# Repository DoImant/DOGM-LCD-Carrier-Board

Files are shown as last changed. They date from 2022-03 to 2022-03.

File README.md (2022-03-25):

# Carrier board for displays of the DOGMxxxxA series.

These DOGM text displays are available in variants with 1x8 (EA DOGM081x-A), 2x16 (EA DOGM162x-A) 
and 3x16 characters (EA DOGM163x-A). The carrier board is suitable for all three variants.

This board should support all backlights (white, yellow/green, blue, red, amber, rgb full color),
but only amber was tested. The display must be connected with 3.3V.
The data transmission to the display takes place via the SPI protocol.

## DOGM LCD Datasheet

[Datasheet](https://github.com/DoImant/Stuff/blob/main/DOGM-LCD-Carrier-Board/Datasheet/dogm-lcd-eng.pdf)

## Pictures
DOGM LCD with Backlightmodule
LCD and Backlight

Carrier board front
Carrierboard front side

Carrier board back
Carrierboard back side

Carrier board with DOGM LCD
Carrier board with DOGM LCD

Display with switched off backlight.
No Backlight

Display with low regulated backlight.
Backlight 16

Display with highly regulated backlight.
Backlight 255

## Arduino Library for DOGMxxxxA Devices

[Library] (https://github.com/DoImant/Stuff/tree/main/DOGM-LCD-Carrier-Board/Arduino-Library/DOGM_7036)

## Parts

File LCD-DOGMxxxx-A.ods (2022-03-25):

Source: | C:\Users\Kai\HiDrive\users\kai-r\Elektronik\KiCad\v6\1Projects\LCD-DOGMxxxx-A\LCD-DOGMxxxx-A.kicad_sch
Date: | 24.03.2022 17:09:03
Tool: | Eeschema (6.0.4)
Generator: | D:\Programme\KiCad6\bin\scripting\plugins/bom_csv_grouped_by_value.py
Component Count: | 18
Individual Components:
Item | Qty | Reference(s) | Value | LibPart | Footprint | Datasheet
 |  | C1 | 1u | Device:C_Small | Capacitor_SMD:C_1206_3216Metric_Pad1.33x1.80mm_HandSolder | ~
 |  | C2 | 1u | Device:C_Small | Capacitor_SMD:C_1206_3216Metric_Pad1.33x1.80mm_HandSolder | ~
 |  | H1 | MountingHole | Mechanical:MountingHole | MountingHole:MountingHole_3.2mm_M3 | ~
 |  | H2 | MountingHole | Mechanical:MountingHole | MountingHole:MountingHole_3.2mm_M3 | ~
 |  | H3 | MountingHole | Mechanical:MountingHole | MountingHole:MountingHole_3.2mm_M3 | ~
 |  | H4 | MountingHole | Mechanical:MountingHole | MountingHole:MountingHole_3.2mm_M3 | ~
 |  | J1 | Conn_01x05 | Connector_Generic:Conn_01x10 | Connector_PinHeader_2.54mm:PinHeader_1x10_P2.54mm_Vertical | ~
 |  | Q1 | BC847 | Transistor_BJT:BC847 | Package_TO_SOT_SMD:SOT-23 | http://www.infineon.com/dgdl/Infineon-BC847SERIES_BC848SERIES_BC849SERIES_BC850SERIES-DS-v01_01-en.pdf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
 |  | Q2 | BC847 | Transistor_BJT:BC847 | Package_TO_SOT_SMD:SOT-23 | http://www.infineon.com/dgdl/Infineon-BC847SERIES_BC848SERIES_BC849SERIES_BC850SERIES-DS-v01_01-en.pdf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
 |  | Q3 | BC847 | Transistor_BJT:BC847 | Package_TO_SOT_SMD:SOT-23 | http://www.infineon.com/dgdl/Infineon-BC847SERIES_BC848SERIES_BC849SERIES_BC850SERIES-DS-v01_01-en.pdf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
 |  | R1 | 470 | Device:R | Resistor_SMD:R_1206_3216Metric_Pad1.30x1.75mm_HandSolder | ~
 |  | R2 | 470 | Device:R | Resistor_SMD:R_1206_3216Metric_Pad1.30x1.75mm_HandSolder | ~
 |  | R3 | 470 | Device:R | Resistor_SMD:R_1206_3216Metric_Pad1.30x1.75mm_HandSolder | ~
 |  | R4 | 470 | Device:R | Resistor_SMD:R_1206_3216Metric_Pad1.30x1.75mm_HandSolder | ~
 |  | R5 | nach Farbe | Device:R | Resistor_SMD:R_1206_3216Metric_Pad1.30x1.75mm_HandSolder | ~
 |  | R6 | 24R | Device:R | Resistor_SMD:R_1206_3216Metric_Pad1.30x1.75mm_HandSolder | ~
 |  | R7 | nach Farbe | Device:R | Resistor_SMD:R_1206_3216Metric_Pad1.30x1.75mm_HandSolder | ~
 |  | U1 | EA_DOGM081x-A | MyDisplay_Character:EA_DOGM081x-A | MyDisplay:EA_DOGMxxxx-A_55x27mm_P2.54 | https://cdn-reichelt.de/documents/datenblatt/A500/DOG-M%281%29.pdf
Collated Components:
Item | Qty | Reference(s) | Value | LibPart | Footprint | Datasheet
1 | 2 | C1, C2 | 1u | Device:C_Small | Capacitor_SMD:C_1206_3216Metric_Pad1.33x1.80mm_HandSolder | ~
2 | 4 | H1, H2, H3, H4 | MountingHole | Mechanical:MountingHole | MountingHole:MountingHole_3.2mm_M3 | ~
3 | 1 | J1 | Conn_01x05 | Connector_Generic:Conn_01x10 | Connector_PinHeader_2.54mm:PinHeader_1x10_P2.54mm_Vertical | ~
4 | 3 | Q1, Q2, Q3 | BC847 | Transistor_BJT:BC847 | Package_TO_SOT_SMD:SOT-23 | http://www.infineon.com/dgdl/Infineon-BC847SERIES_BC848SERIES_BC849SERIES_BC850SERIES-DS-v01_01-en.pdf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
5 | 4 | R1, R2, R3, R4 | 470 | Device:R | Resistor_SMD:R_1206_3216Metric_Pad1.30x1.75mm_HandSolder | ~
6 | 2 | R5, R7 | nach Farbe | Device:R | Resistor_SMD:R_1206_3216Metric_Pad1.30x1.75mm_HandSolder | ~
7 | 1 | R6 | 24R | Device:R | Resistor_SMD:R_1206_3216Metric_Pad1.30x1.75mm_HandSolder | ~
8 | 1 | U1 | EA_DOGM081x-A | MyDisplay_Character:EA_DOGM081x-A | MyDisplay:EA_DOGMxxxx-A_55x27mm_P2.54 | https://cdn-reichelt.de/documents/datenblatt/A500/DOG-M%281%29.pdf

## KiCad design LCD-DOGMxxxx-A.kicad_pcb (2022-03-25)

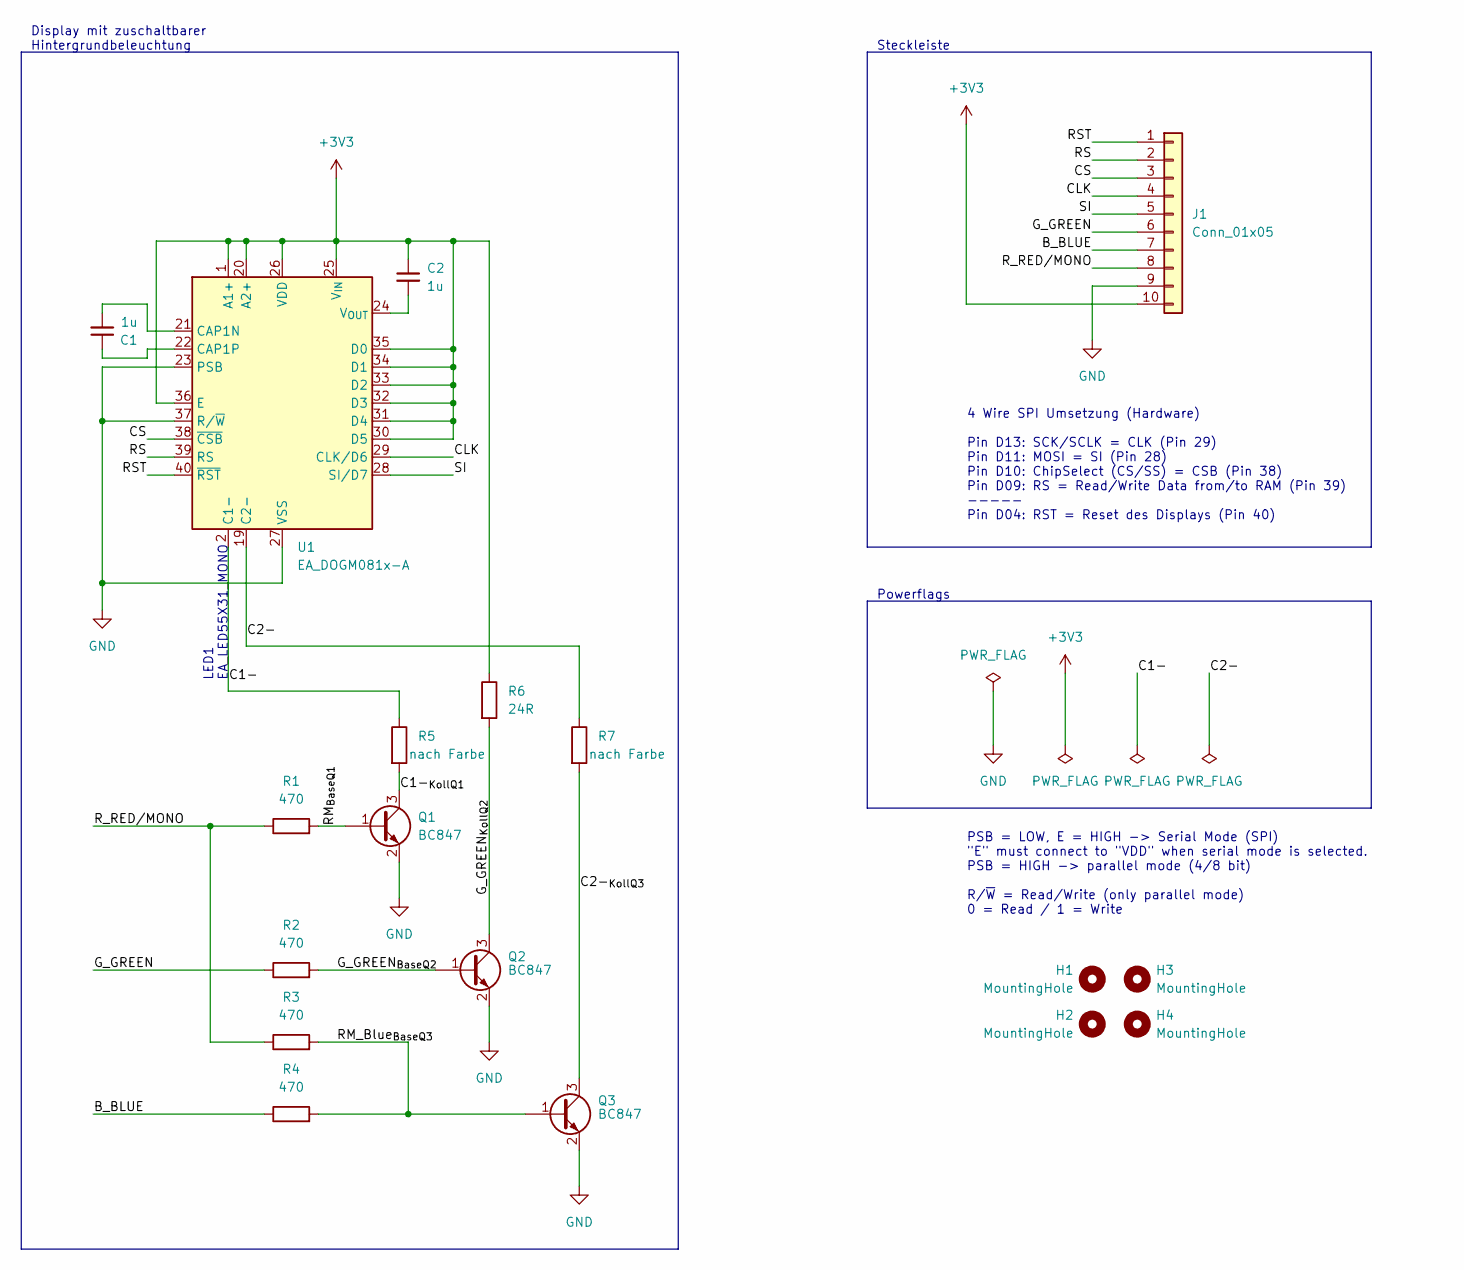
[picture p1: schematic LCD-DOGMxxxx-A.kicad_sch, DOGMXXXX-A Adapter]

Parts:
C1, C2: 1u; C_1206_3216Metric_Pad1.33x1.80mm_HandSolder
H1, H2, H3, H4: MountingHole; MountingHole_3.2mm_M3
J1: Conn_01x05; PinHeader_1x10_P2.54mm_Vertical
Q1, Q2, Q3: BC847; SOT-23
R1, R2, R3, R4: 470; R_1206_3216Metric_Pad1.30x1.75mm_HandSolder
R5, R7: nach Farbe; R_1206_3216Metric_Pad1.30x1.75mm_HandSolder
R6: 24R; R_1206_3216Metric_Pad1.30x1.75mm_HandSolder
U1: EA_DOGM081x-A; EA_DOGMxxxx-A_55x27mm_P2.54

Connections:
+3V3: C2.1, J1.10, R6.1, U1.1 (A1+), U1.20 (A2+), U1.25 (V_{IN}), U1.26 (VDD), U1.30 (D5), U1.31 (D4), U1.32 (D3), U1.33 (D2), U1.34 (D1), U1.35 (D0), U1.36 (E)
/B_BLUE: J1.7, R4.1
/C1-: R5.1, U1.2 (C1-)
/C1-_{KollQ1}: Q1.3 (C), R5.2
/C2-: R7.1, U1.19 (C2-)
/C2-_{KollQ3}: Q3.3 (C), R7.2
/CLK: J1.4, U1.29 (CLK/D6)
/CS: J1.3, U1.38 (~CSB)
/G_GREEN: J1.6, R2.1
/G_GREEN_{BaseQ2}: Q2.1 (B), R2.2
/G_GREEN_{KollQ2}: Q2.3 (C), R6.2
/RM_Blue_{BaseQ3}: Q3.1 (B), R3.2, R4.2
/RM_{BaseQ1}: Q1.1 (B), R1.2
/RS: J1.2, U1.39 (RS)
/RST: J1.1, U1.40 (~RST)
/R_RED/MONO: J1.8, R1.1, R3.1
/SI: J1.5, U1.28 (SI/D7)
GND: J1.9, Q1.2 (E), Q2.2 (E), Q3.2 (E), U1.23 (PSB), U1.27 (VSS), U1.37 (R/~W)
unnamed: C1.1, U1.22 (CAP1P)
unnamed: C1.2, U1.21 (CAP1N)
unnamed: C2.2, U1.24 (V_{OUT})

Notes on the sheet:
PSB = LOW, E = HIGH -> Serial Mode (SPI) "E" must connect to "VDD" when serial mode is selected. PSB = HIGH -> parallel mode (4/8 bit) R/~{W} = Read/Write (only parallel mode) 0 = Read / 1 = Write
Steckleiste
Display mit zuschaltbarer Hintergrundbeleuchtung
LED1 EA_LED55X31_MONO
4 Wire SPI Umsetzung (Hardware) Pin D13: SCK/SCLK = CLK (Pin 29) Pin D11: MOSI = SI (Pin 28) Pin D10: ChipSelect (CS/SS) = CSB (Pin 38) Pin D09: RS = Read/Write Data from/to RAM (Pin 39) ----- Pin D04: RST = Reset des Displays (Pin 40)
Powerflags

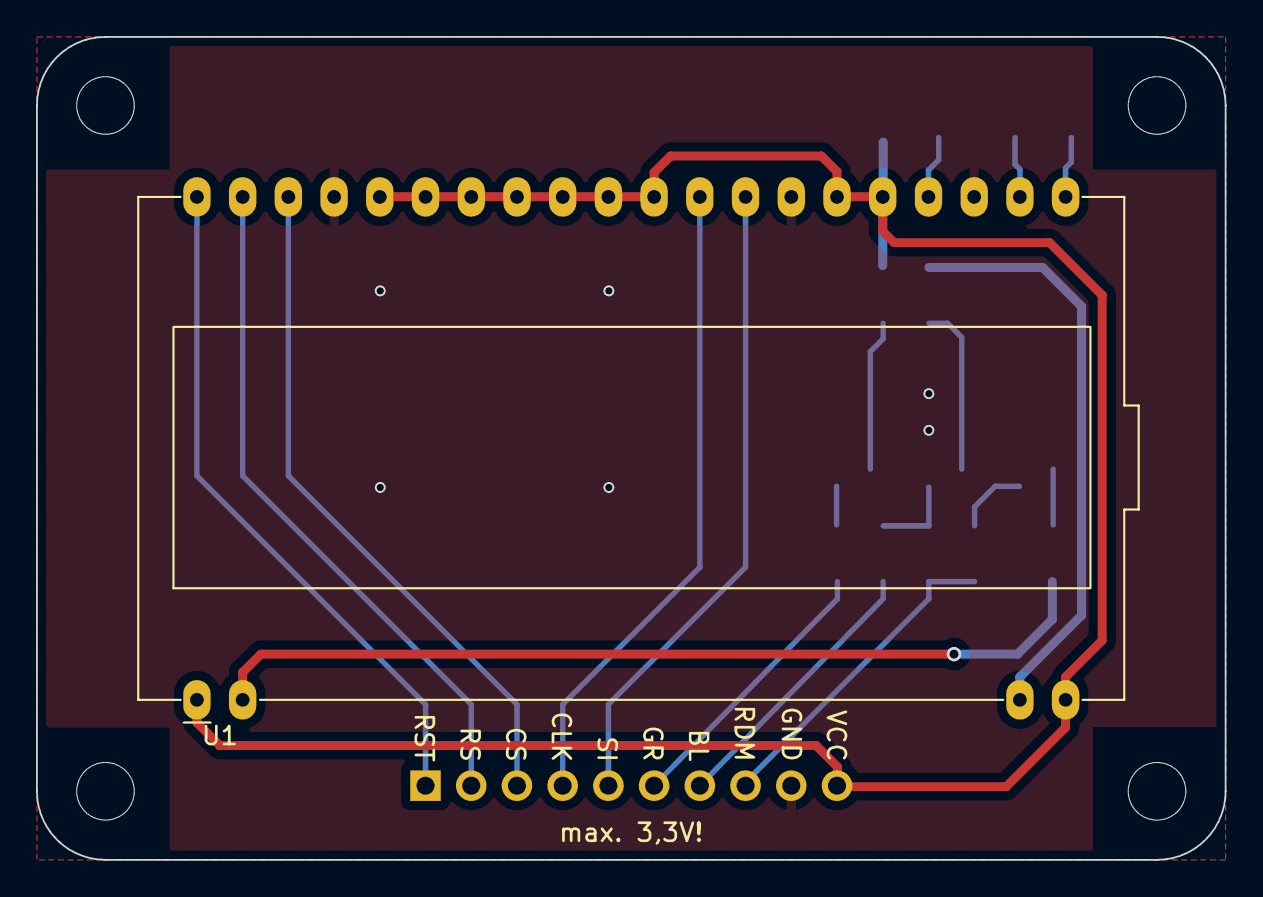
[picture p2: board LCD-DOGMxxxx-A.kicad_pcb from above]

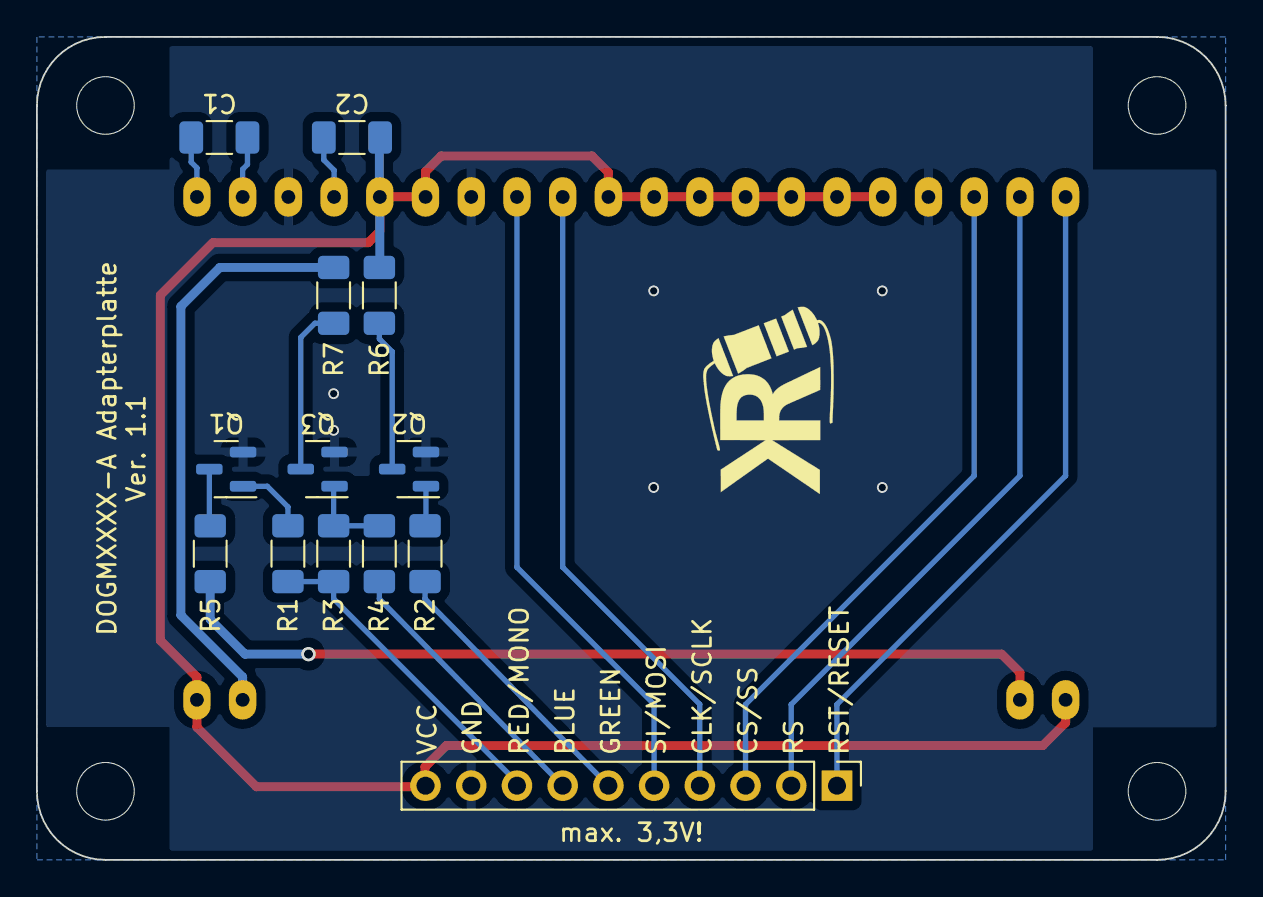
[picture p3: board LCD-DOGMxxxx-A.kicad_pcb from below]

Board: 2 copper layers, 66.0 x 45.7 mm, 18 parts (13 on the bottom side), 21 nets.
